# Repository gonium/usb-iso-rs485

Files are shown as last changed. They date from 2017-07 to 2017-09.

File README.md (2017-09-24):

# An isolated USB-RS485 adapter

I connected a lot of USB-RS485 adapters to my [smart meter readout
software](https://github.com/gonium/gosdm630) and wasn't happy. Either
the device is cheap and broken or works but is very expensive. The
supercheap adaptors from China often provice no ground connection, one
worked fine, another one was unstable. Both did not adhere to the USB
spec (90mA initial current draw limit). On the other hand, industrial
adaptors like the Meilhaus RedCOM USB-COMi-SI or the ADAM 4561 isolate
the RS-485 bus from the USB line and work extremely reliable. But they
are really expensive.

This project aims to create an adaptor that works well and is reasonably
priced. We use the following components:

* An FTDI FT232L provides the USB-UART interface and can be configured
for RS485 operation.
* An [Analog Devices
ADM2582E](http://www.analog.com/media/en/technical-documentation/data-sheets/ADM2582E_2587E.pdf)
isolates the RS485 bus and generates the supply voltage for the bus.
Please note: this device is rather expensive, but Analog Devices will
send you samples at no cost.
* We use WAGO 233 series connectors to connect to the RS485 bus

The first prototype looks like this:

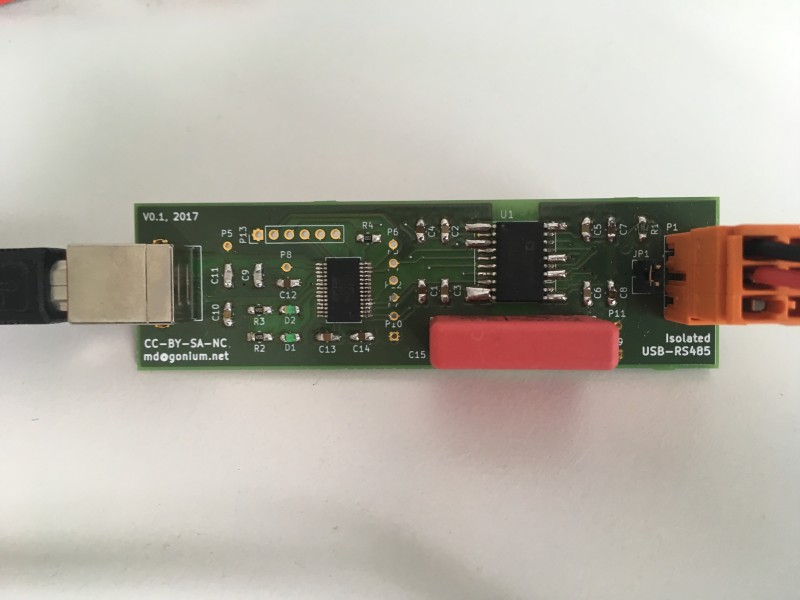
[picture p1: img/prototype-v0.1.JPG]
First prototype


The PCB is too big, and I don't need all those test points any more.
Therefore, I have build the second prototype. Please note that the board
is slightly smaller, has a different WAGO connector and unpopulated
footprints for protection diodes:

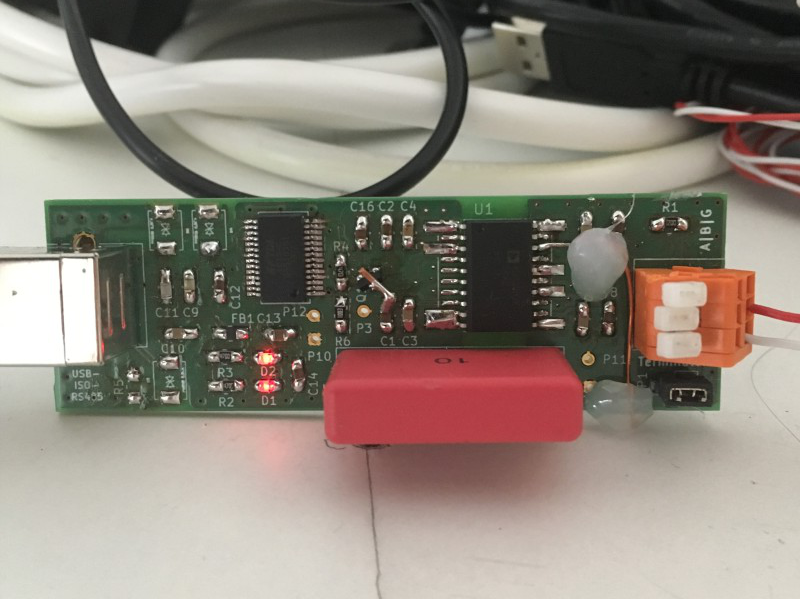
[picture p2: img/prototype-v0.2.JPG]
Second prototype


The second prototype works quite well. Unfortunately, the holes for the
WAGO connector are too small -- I needed to drill them bigger. While
doing so, I destroyed a connection to the "A" pin - the copper wire to
the right of the WAGO connector replaces the PCB trace I destroyed. In
addition, the footprint for the MOSFET is wrong.

Minor layout changes are needed, but the principle is solid.

# TODO

* Copy all footprints to project library
* Footprint of MOSFET is wrong
* Increase hole diameter for WAGO connector
* Fix position of silkscreen on bottom layer

# FTDI configuration.

The FTDI chip needs to be configured in order to work in this
application. Specifically, the following changes need to be written into
its EEPROM:

* CBUS3 must be set to PwrEN. This ensures that the device draws only 90
mA when plugged in. After completing the USB enumeration process, this
pin triggers the onboard MOSFET and the remainder of the board is
powered up.
* CBUS4 must be set to TxDEN. The FTDI toggles the nRE pin of the ADM2582.

You can use [Mark Lord's ft232r_prog](http://rtr.ca/ft232r/) to change
the EEPROM settings. In order to see the current EEPROM content, use

    $ ft232r_prog --verbose --dump --old-vid 0x0403 --old-pid 0x6001

In order to set CBUS3 to PwrEN, CBUS4 to TxDEN, high-current-io off and
the maximum power consumption to 300 mA, use

    $ ft232r_prog --verbose --dump --old-vid 0x0403 --old-pid 0x6001 \
		--cbus3 PwrEn --cbus4 TxDEN --high-current-io off --max-bus-power 300

On Linux I could successfully compile the binary just by typing
``make`` and using it as described above. On Mac OS X, I needed to add
``/usr/local`` to the Makefile. The top two lines now read like this:

    CFLAGS = -Wall -O2 -s -Werror -I/usr/local/include
    LDFLAGS = -L/usr/local/lib -lusb -lftdi -s

In my case, a FTDI driver claimed the device, preventing the
``ft232r_prog`` command to communicate with the FTDI. You can list the
FTDI-related kernel extensions using

    $ kextstat | grep FTDI
		156    0 0xffffff7f83606000 0x8000     0x8000     com.FTDI.driver.FTDIUSBSerialDriver (2.2.16) 0AB01558-B114-9EF2-1CD9-A13CFA557737 <137 55 5 4 3 1>

Then, to unload the driver, use

    $ sudo kextunload -b com.FTDI.driver.FTDIUSBSerialDriver

for all FTDI drivers you found.

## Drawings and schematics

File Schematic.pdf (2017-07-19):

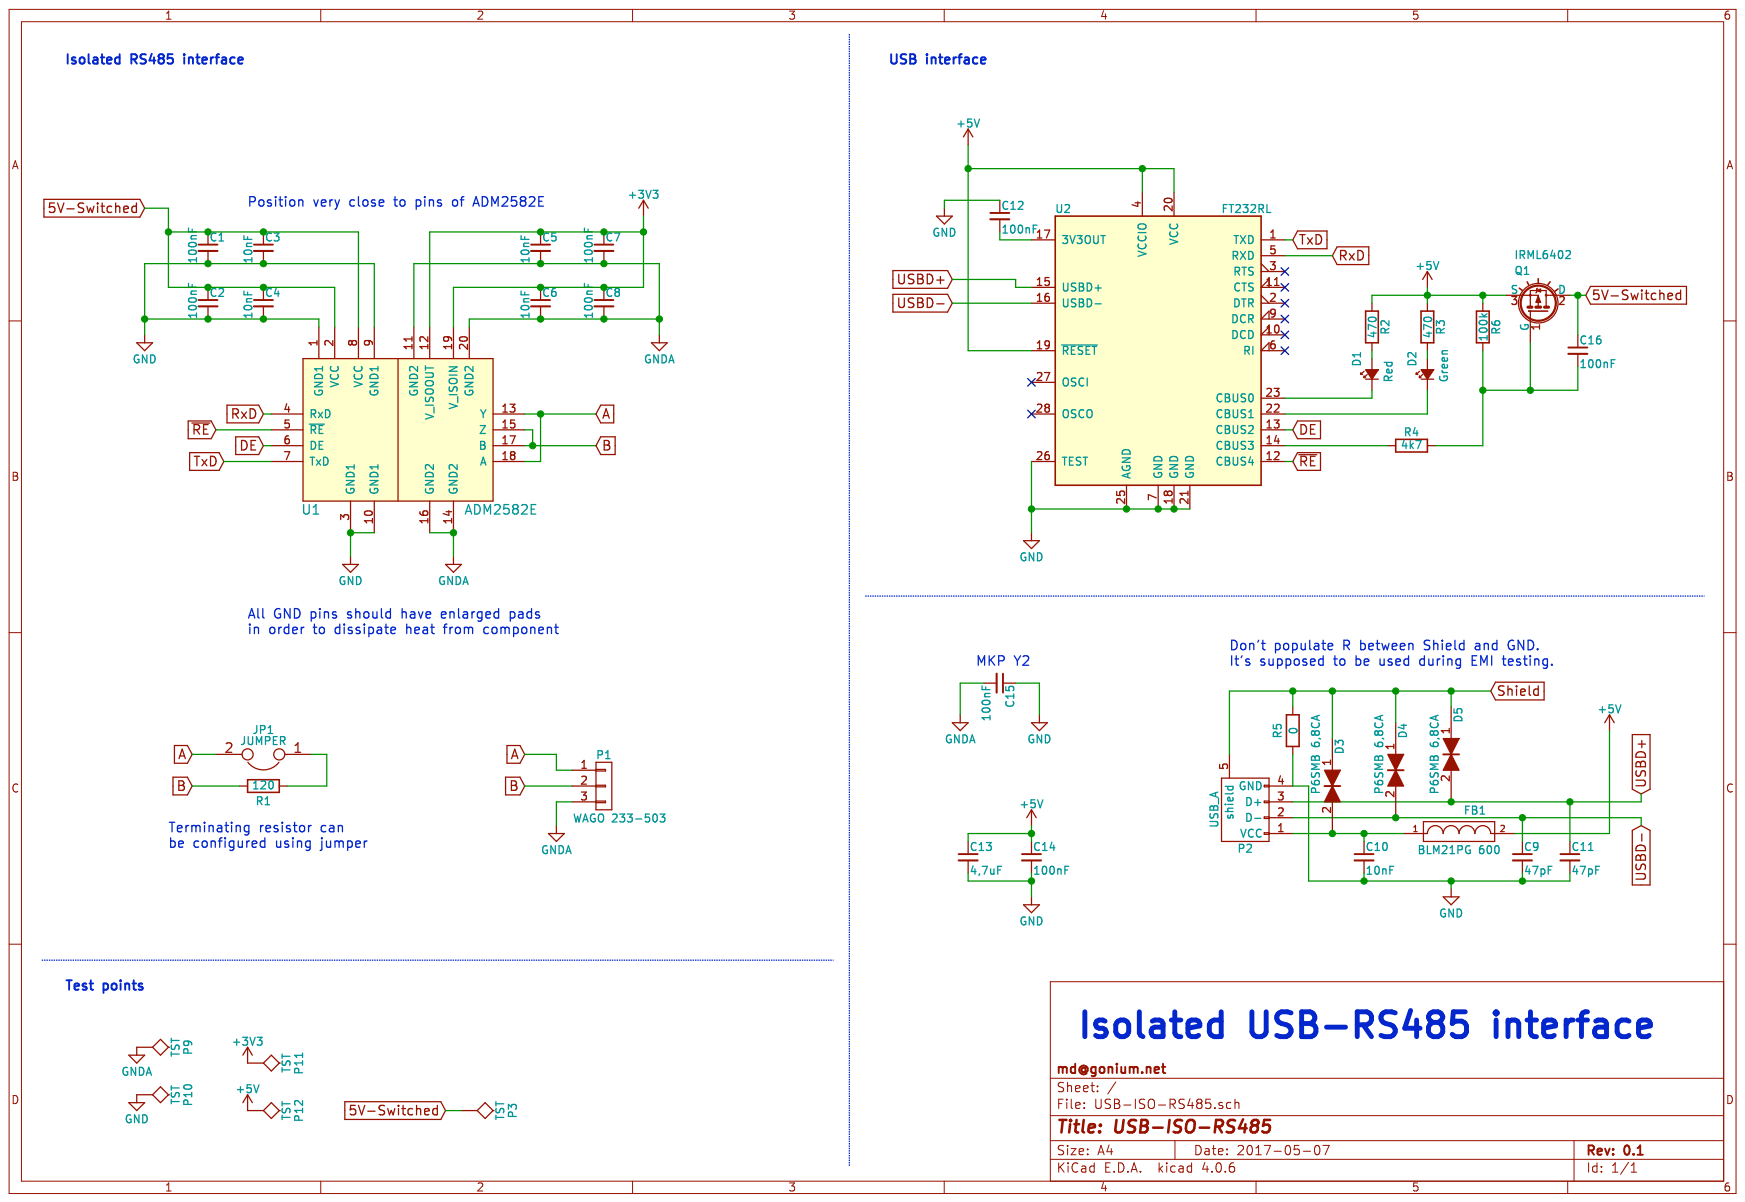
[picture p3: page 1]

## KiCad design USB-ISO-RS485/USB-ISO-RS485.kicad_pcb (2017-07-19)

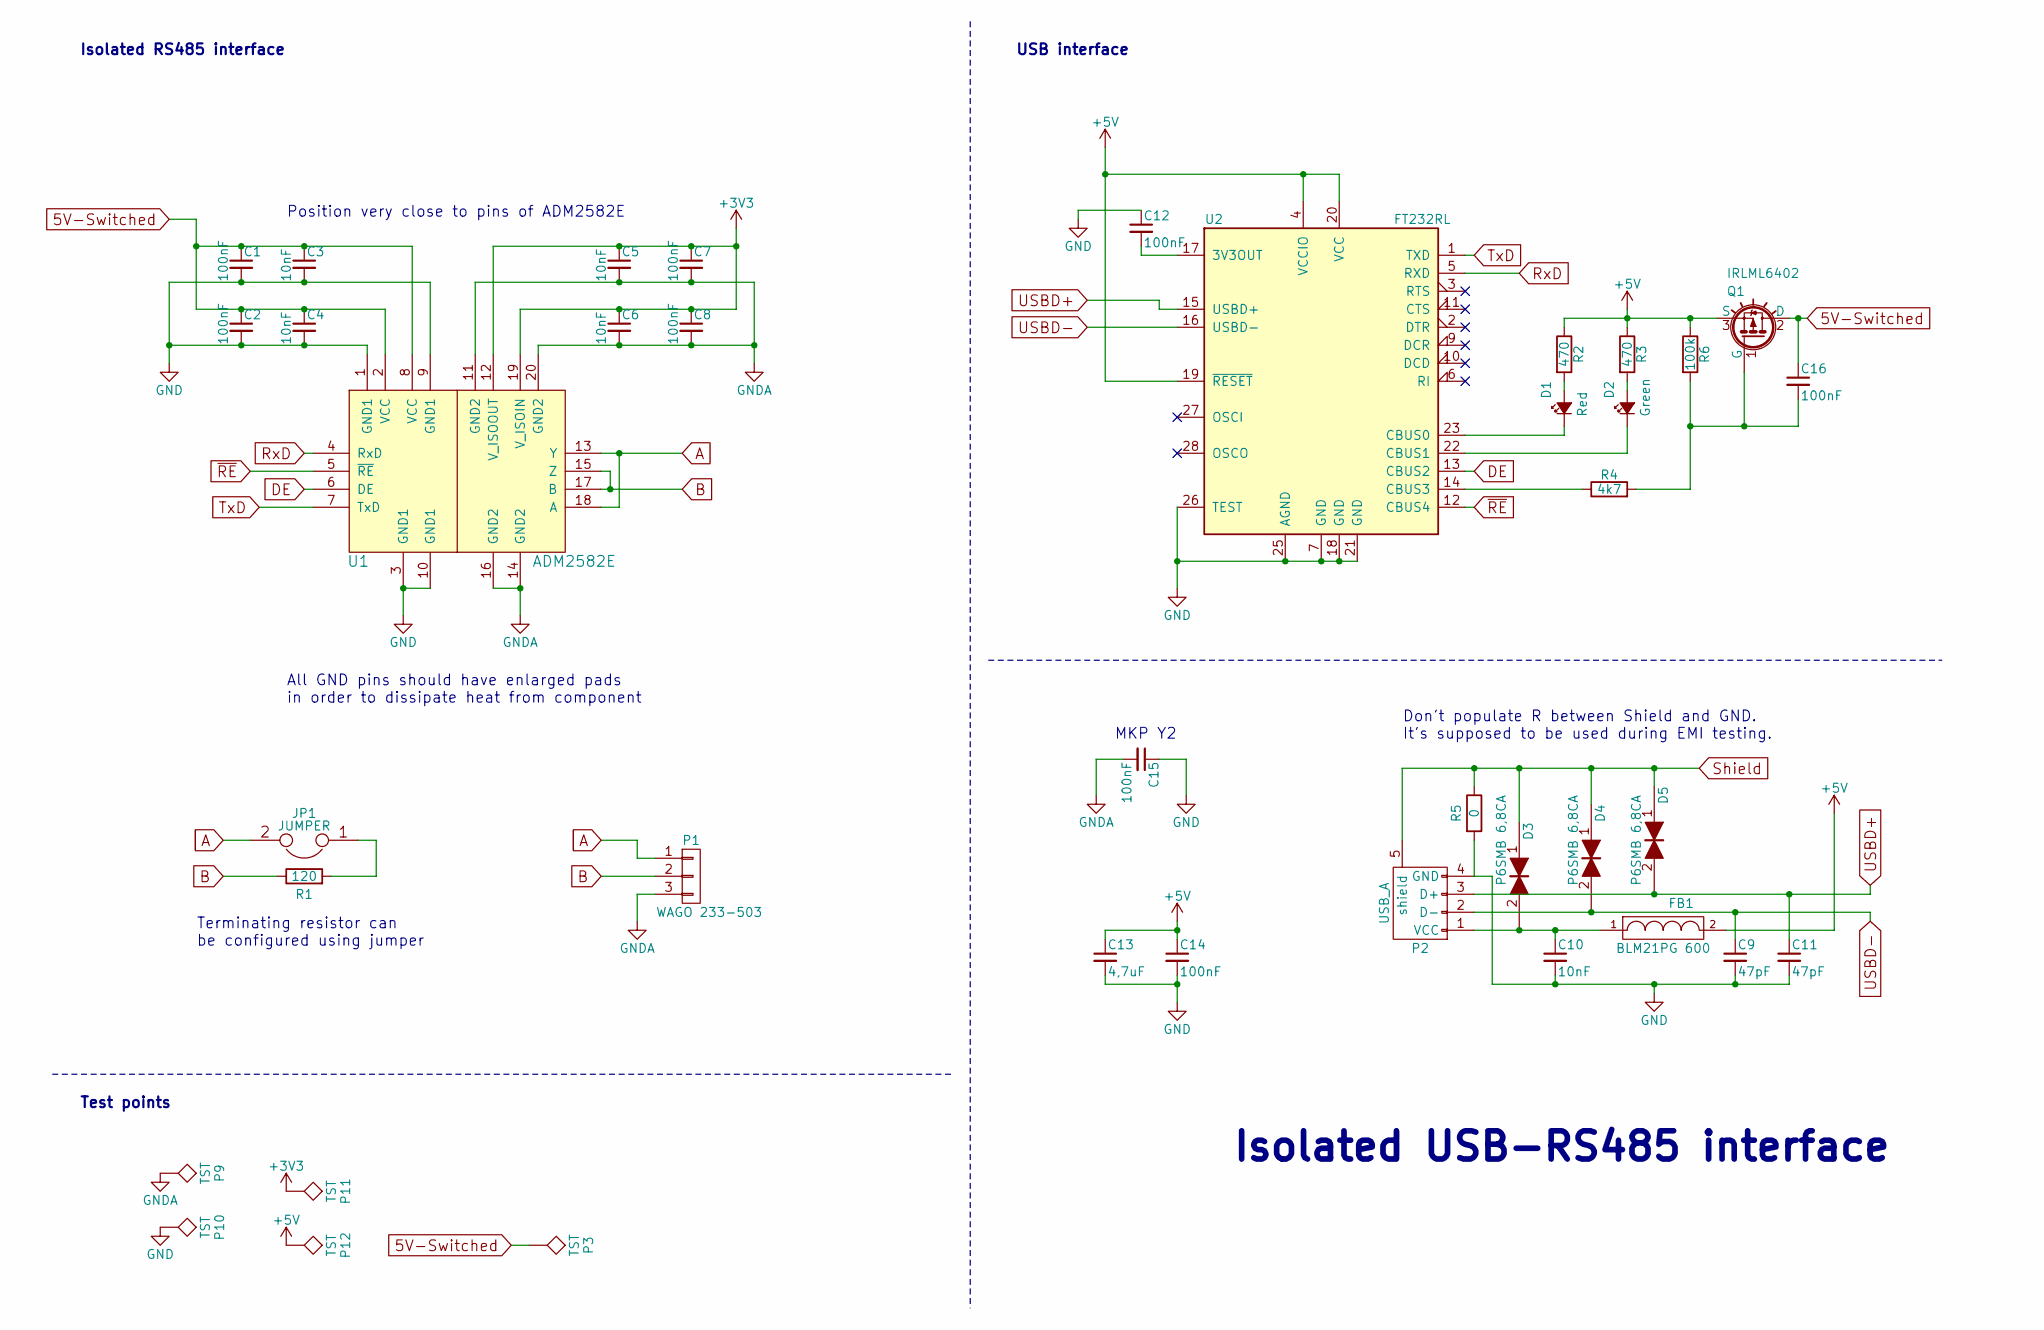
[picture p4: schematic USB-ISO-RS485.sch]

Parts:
C1, C2, C7, C8, C12, C14, C16: 100nF; C_0805_HandSoldering
C3, C4, C5, C6, C10: 10nF; C_0805_HandSoldering
C9, C11: 47pF; C_0805_HandSoldering
C13: 4,7uF; C_0805_HandSoldering
C15: 100nF; C_Rect_L26.5mm_W7.0mm_P22.50mm_MKS4
D1: Red; LED_0805
D2: Green; LED_0805
D3, D4, D5: P6SMB 6,8CA; P6SMB6,8CA
FB1: BLM21PG 600; R_0805_HandSoldering
JP1: JUMPER; Pin_Header_Straight_1x02_Pitch2.54mm
P1: WAGO 233-503; WAGO233-503
P2: USB_A; USB_B
P3, P9, P10, P11, P12: TST; Measurement_Point_Round-TH_Small
Q1: IRLML6402
R1: 120; R_0805_HandSoldering
R2, R3: 470; R_0805_HandSoldering
R4: 4k7; R_0805_HandSoldering
R5: 0; R_0805_HandSoldering
R6: 100k; R_0805_HandSoldering
U1: ADM2582E; ADM2582E-SOIC20W-Thermal-Correct
U2: FT232RL; SSOP-28_5.3x10.2mm_Pitch0.65mm

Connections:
5V-Switched: C1.1, C2.1, C3.1, C4.1, C16.1, P3.1, Q1.2 (D), U1.2 (VCC), U1.8 (VCC)
+3V3: C5.1, C6.1, C7.1, C8.1, P11.1, U1.12 (V_ISOOUT), U1.19 (V_ISOIN)
+5V: C13.1, C14.1, FB1.2, P12.1, Q1.3 (S), R2.1, R3.1, R6.1, U2.4 (VCCIO), U2.19 (~RESET~), U2.20 (VCC)
A: JP1.2, P1.1, U1.13 (Y), U1.18 (A)
B: P1.2, R1.1, U1.15 (Z), U1.17 (B)
DE: U1.6 (DE), U2.13 (CBUS2)
GND: C1.2, C2.2, C3.2, C4.2, C9.2, C10.2, C11.2, C12.1, C13.2, C14.2, C15.1, P2.4 (GND), P10.1, R5.2, U1.1 (GND1), U1.3 (GND1), U1.9 (GND1), U1.10 (GND1), U2.7 (GND), U2.18 (GND), U2.21 (GND), U2.25 (AGND), U2.26 (TEST)
GNDA: C5.2, C6.2, C7.2, C8.2, C15.2, P1.3, P9.1, U1.11 (GND2), U1.14 (GND2), U1.16 (GND2), U1.20 (GND2)
unnamed: C10.1, D3.2, FB1.1, P2.1 (VCC)
unnamed: C12.2, U2.17 (3V3OUT)
unnamed: C16.2, Q1.1 (G), R4.2, R6.2
unnamed: D1.1 (K), U2.23 (CBUS0)
unnamed: D1.2 (A), R2.2
unnamed: D2.1 (K), U2.22 (CBUS1)
unnamed: D2.2 (A), R3.2
unnamed: JP1.1, R1.2
unnamed: R4.1, U2.14 (CBUS3)
RxD: U1.4 (RxD), U2.5 (RXD)
Shield: D3.1, D4.1, D5.1, P2.5 (shield), R5.1
TxD: U1.7 (TxD), U2.1 (TXD)
USBD+: C11.1, D5.2, P2.3 (D+), U2.15 (USBD+)
USBD-: C9.1, D4.2, P2.2 (D-), U2.16 (USBD-)
~RE: U1.5 (~RE), U2.12 (CBUS4)

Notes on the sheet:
Position very close to pins of ADM2582E
All GND pins should have enlarged pads in order to dissipate heat from component
Terminating resistor can be configured using jumper
USB interface
Isolated RS485 interface
Isolated USB-RS485 interface
Test points
MKP Y2
Don't populate R between Shield and GND. It's supposed to be used during EMI testing.

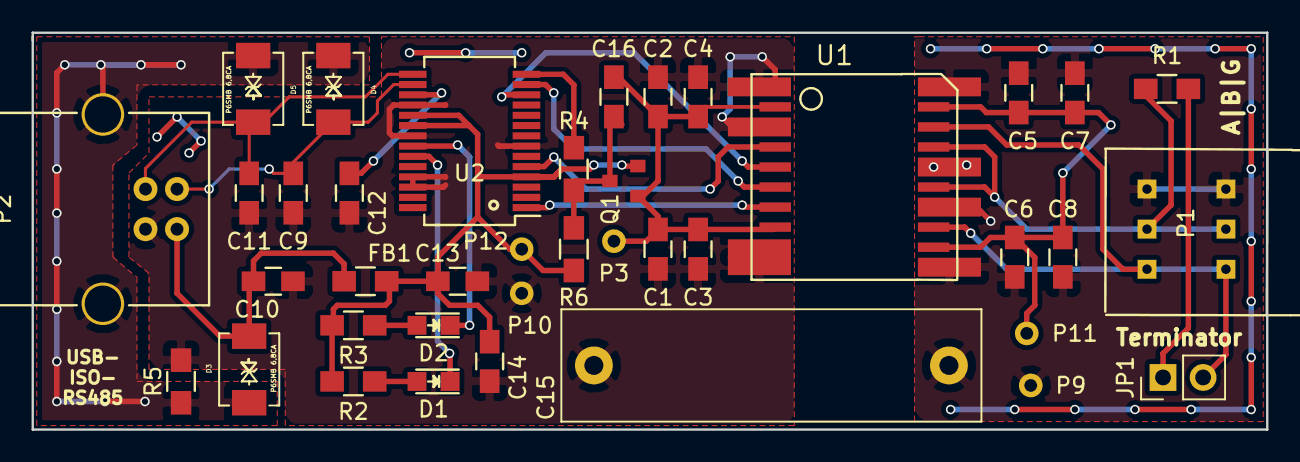
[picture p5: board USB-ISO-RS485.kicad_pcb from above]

Board: 2 copper layers, 78.2 x 25.1 mm, 39 parts (0 on the bottom side), 23 nets.

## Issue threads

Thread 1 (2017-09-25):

Boards

frankrichter, 2017-09-25:
Hi,

wird es doch keine Boards zu kaufen geben? Habe gesehen dass die Ankündigung aus der Readme verschwunden ist.

Grüße
Frank

l33tn00b, 2017-11-13:
Empfehle dazu Aisler.net
Akzeptiert KiCAD Boards und macht die Platinen zu einem anständigen Preis. Teile gibt's fast alle bei Digikey. Mit zwei ADM hat man ja schon einen guten Batzen des Preises für freien Versand.

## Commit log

2017-05-07 schematic completed
    [USB-ISO-RS485.kicad_pcb, USB-ISO-RS485.sch]
2017-05-07 Added UART interface header, exported schematic as PDF
    [USB-ISO-RS485.sch]
2017-05-13 assigned all footprints
    [USB-ISO-RS485.kicad_pcb, USB-ISO-RS485.sch]
2017-05-14 broken layout - ADM2582E footprint to narrow
    [USB-ISO-RS485.kicad_pcb, USB-ISO-RS485.sch]
2017-05-14 added corrected footprint, rerouted board
    [USB-ISO-RS485.kicad_pcb, USB-ISO-RS485.sch]
2017-05-30 completed TODO list, added commandline example for setting the FTDI bus power report
2017-06-18 added switching USB power, shielding separated, added TVS & EMI filter on USB line
    [USB-ISO-RS485.sch]
2017-06-18 new PDF export
    [USB-ISO-RS485.sch]
2017-06-20 created new footprints & completed association.
    [USB-ISO-RS485.sch]
2017-06-25 v0.2 board layout complete
    [USB-ISO-RS485.kicad_pcb]
2017-07-09 working on v0.2
    [USB-ISO-RS485.kicad_pcb]

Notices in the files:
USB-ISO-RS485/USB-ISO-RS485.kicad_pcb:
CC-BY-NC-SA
